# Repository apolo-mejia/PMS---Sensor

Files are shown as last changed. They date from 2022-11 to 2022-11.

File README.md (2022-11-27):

# PMS_Sensor
Power manage System for Microcontrolles ans sensors, in the scope of Syracuza proyect. 
Features:
- Automatic connetion/disconnection, from Li-ION battery protection,
- Automatic disconnection a battery when a external alimentation is provided,
- Compatible with Energy Harvest, <br>
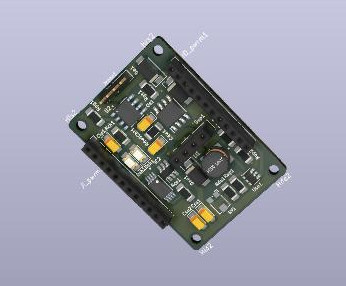
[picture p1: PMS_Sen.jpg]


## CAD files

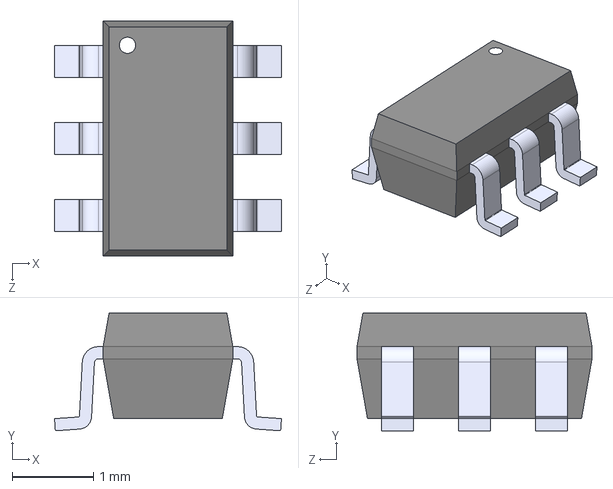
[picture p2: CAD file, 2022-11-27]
DW01A/DW01A.step
2.80 x 1.45 x 2.90 mm

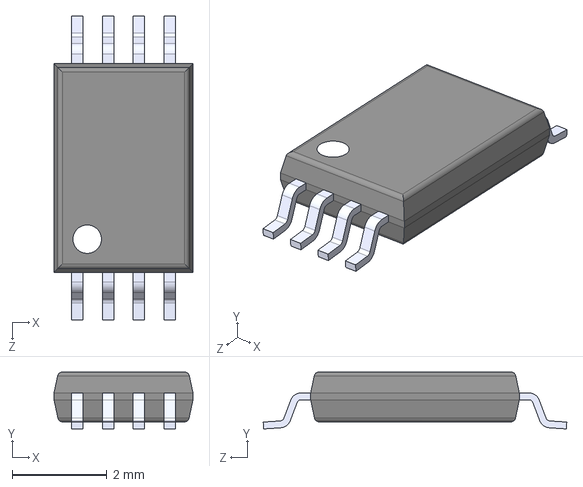
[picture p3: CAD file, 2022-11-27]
FS8205A/FS8205A.step
2.93 x 1.20 x 6.40 mm

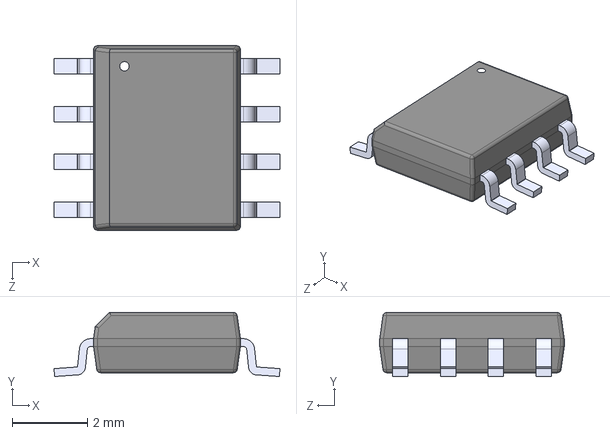
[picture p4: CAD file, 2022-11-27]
TP4056/TP4056.step
6.00 x 1.70 x 4.90 mm

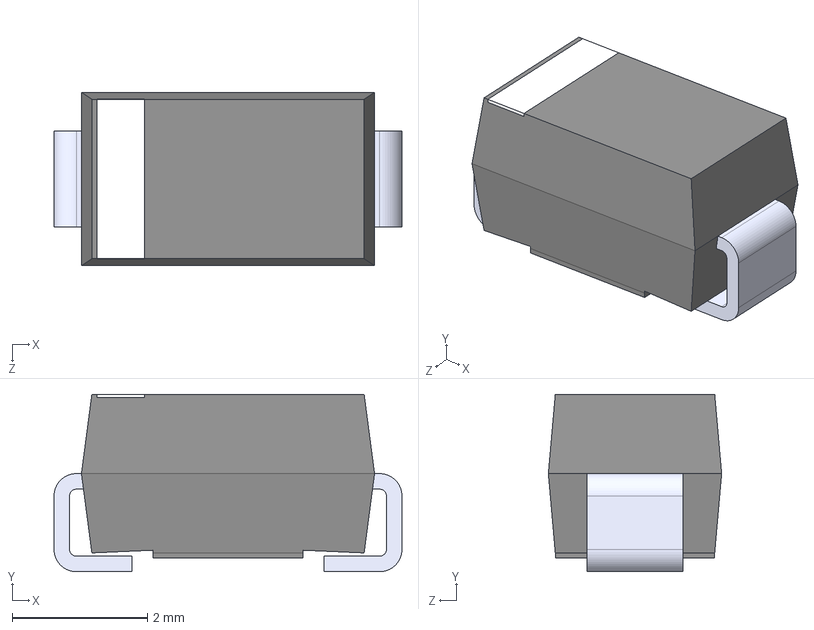
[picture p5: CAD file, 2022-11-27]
US1M-13/US1M-13.step
5.14 x 2.62 x 2.56 mm

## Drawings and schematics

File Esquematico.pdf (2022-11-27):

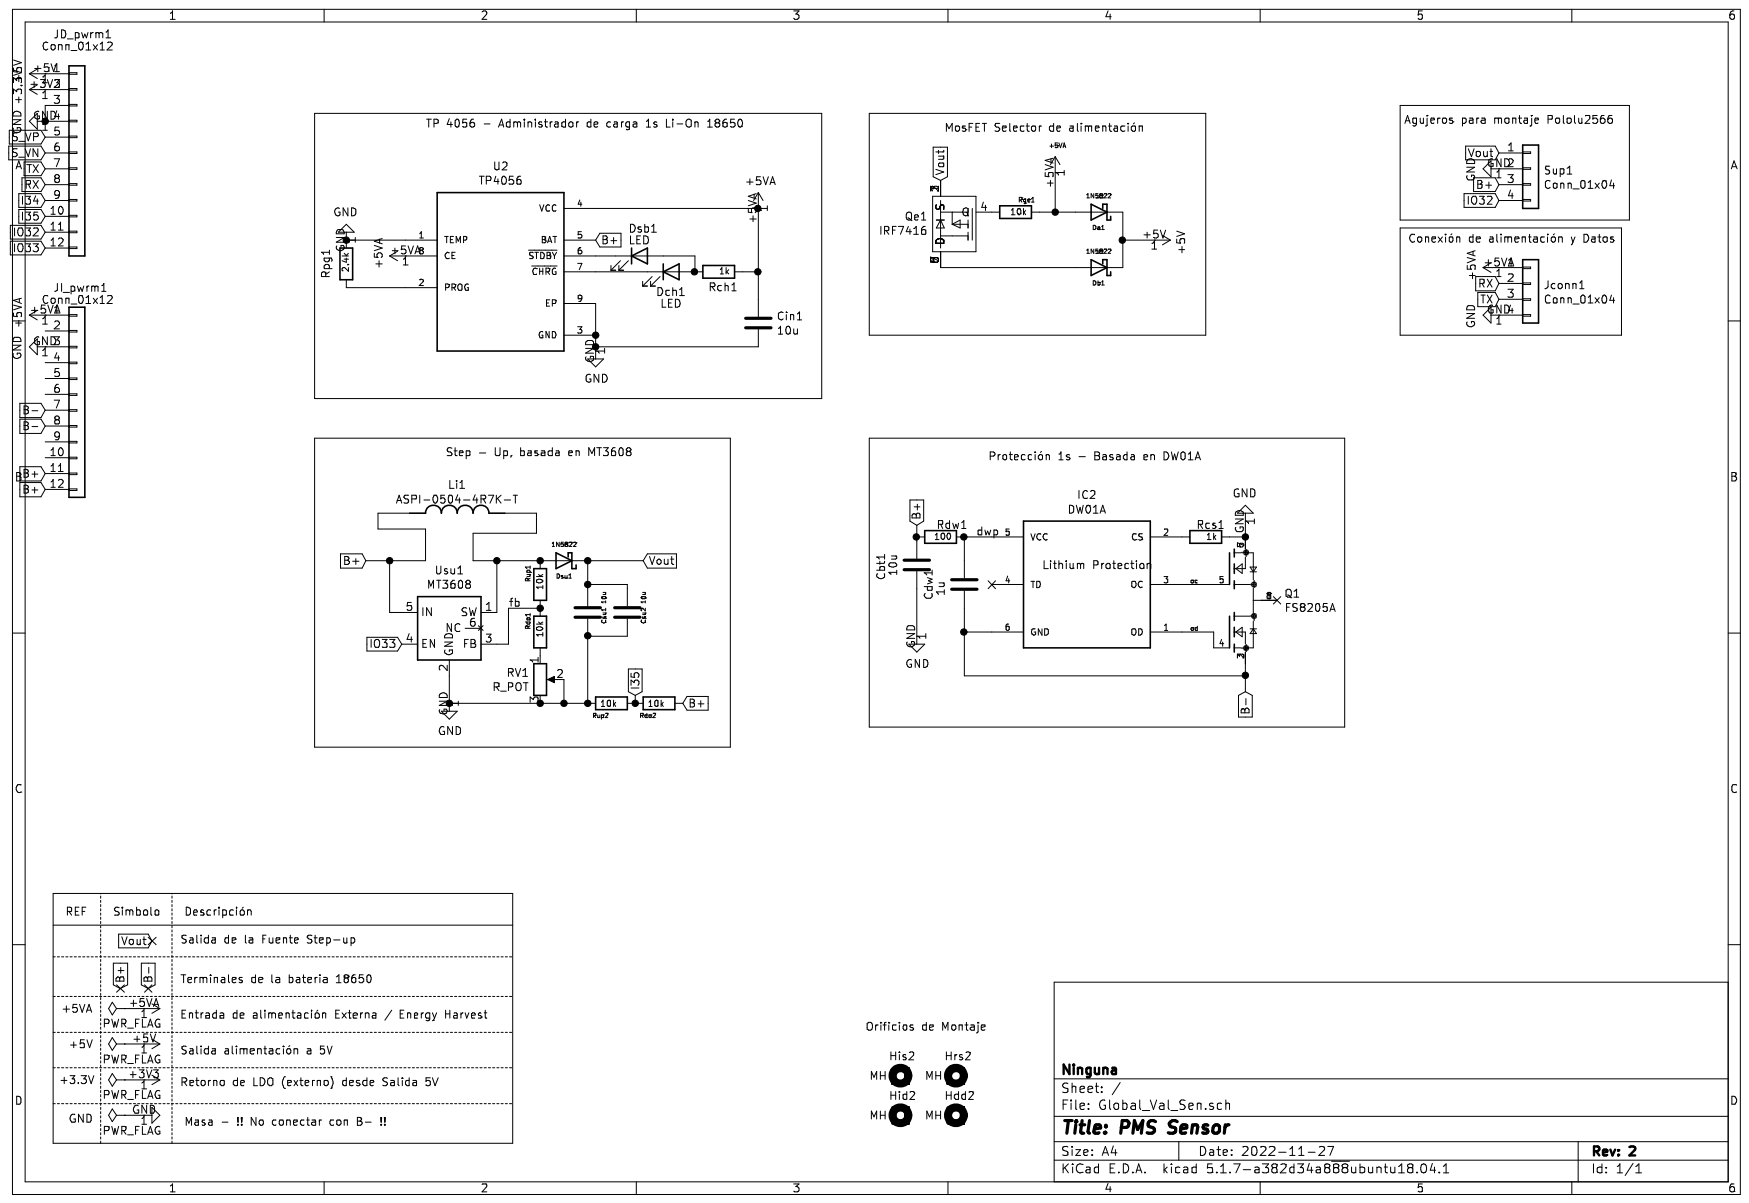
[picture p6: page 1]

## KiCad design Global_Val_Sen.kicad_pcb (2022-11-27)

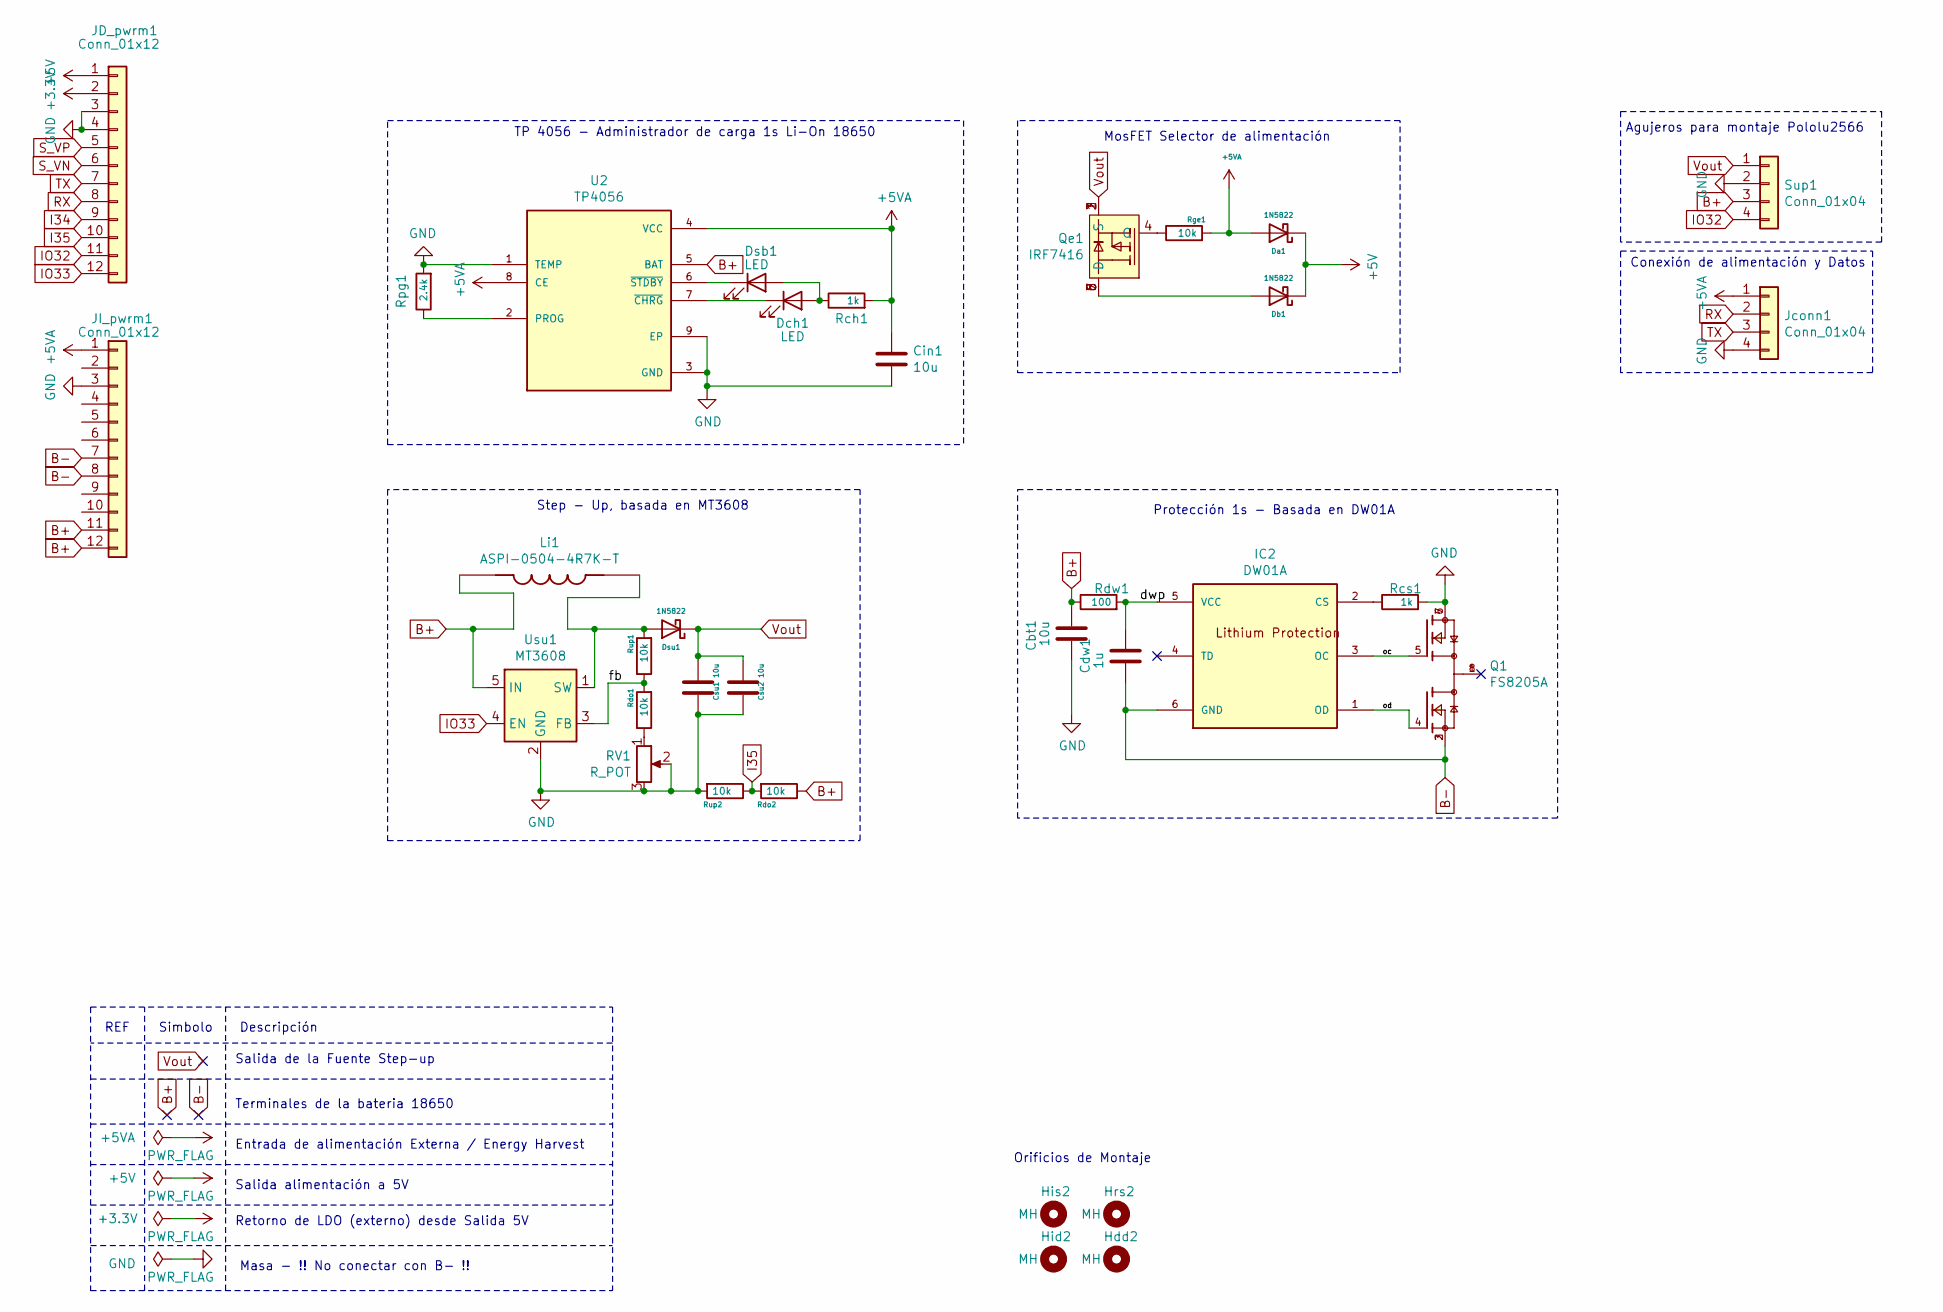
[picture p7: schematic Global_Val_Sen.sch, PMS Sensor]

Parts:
Cbt1: 10u; CP_EIA-3216-10_Kemet-I_Pad1.58x1.35mm_HandSolder
Cdw1: 1u; CP_EIA-3216-10_Kemet-I_Pad1.58x1.35mm_HandSolder
Cin1: 10u; CP_EIA-3216-10_Kemet-I_Pad1.58x1.35mm_HandSolder
Csu1, Csu2: 10u; CP_EIA-3216-10_Kemet-I_Pad1.58x1.35mm_HandSolder
Da1: 1N5822; D_SMA
Db1: 1N5822; D_SMA
Dch1: LED; LED_1206_3216Metric_Castellated
Dsb1: LED; LED_1206_3216Metric_Castellated
Dsu1: 1N5822; D_SMA
Hdd2: MH; MountingHole_2.2mm_M2_DIN965
Hid2: MH; MountingHole_2.2mm_M2_DIN965
His2: MH; MountingHole_2.2mm_M2_DIN965
Hrs2: MH; MountingHole_2.2mm_M2_DIN965
IC2: DW01A; SOT-23-6_Handsoldering
JD_pwrm1: Conn_01x12; PinSocket_1x12_P2.00mm_Vertical
JI_pwrm1: Conn_01x12; PinSocket_1x12_P2.00mm_Vertical
Jconn1: Conn_01x04; PinHeader_1x04_P2.00mm_Vertical
Li1: ASPI-0504-4R7K-T; IND_ASPI-0504-4R7K-T; PARTREV 06.24.13
Q1: FS8205A; SOP65P640X120-8N; PARTREV 1.7
Qe1: IRF7416; SO-8_3.9x4.9mm_P1.27mm
RV1: R_POT; Potentiometer_Bourns_TC33X_Vertical
Rch1: 1k; R_1206_3216Metric_Pad1.30x1.75mm_HandSolder
Rcs1: 1k; R_1206_3216Metric_Pad1.30x1.75mm_HandSolder
Rdo1, Rdo2: 10k; R_1206_3216Metric_Pad1.30x1.75mm_HandSolder
Rdw1: 100; R_1206_3216Metric_Pad1.30x1.75mm_HandSolder
Rge1: 10k; R_1206_3216Metric_Pad1.30x1.75mm_HandSolder
Rpg1: 2.4k; R_1206_3216Metric_Pad1.30x1.75mm_HandSolder
Rup1, Rup2: 10k; R_1206_3216Metric_Pad1.30x1.75mm_HandSolder
Sup1: Conn_01x04; PinSocket_1x04_P2.54mm_Vertical
U2: TP4056; SOP127P600X175-9N
Usu1: MT3608; SOT-23-6

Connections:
+3V3: JD_pwrm1.2
+5V: Da1.1 (K), Db1.1 (K), JD_pwrm1.1
+5VA: Cin1.1, Da1.2 (A), JI_pwrm1.1, Jconn1.1, Rch1.2, Rge1.2, U2.4 (VCC), U2.8 (CE)
/dwp: Cdw1.1, IC2.5 (VCC), Rdw1.2
/fb: Rdo1.2, Rup1.1, Usu1.3 (FB)
/oc: IC2.3 (OC), Q1.5
/od: IC2.1 (OD), Q1.4
B+: Cbt1.1, JI_pwrm1.11, JI_pwrm1.12, Li1.1, Rdo2.1, Rdw1.1, Sup1.3, U2.5 (BAT), Usu1.5 (IN)
B-: Cdw1.2, IC2.6 (GND), JI_pwrm1.7, JI_pwrm1.8, Q1.2, Q1.3
I34: JD_pwrm1.9
I35: JD_pwrm1.10, Rdo2.2, Rup2.1
IO32: JD_pwrm1.11, Sup1.4
IO33: JD_pwrm1.12, Usu1.4 (EN)
unnamed: Db1.2 (A), Qe1.5 (D), Qe1.6 (D), Qe1.7 (D), Qe1.8 (D)
unnamed: Dch1.1 (K), U2.7 (~CHRG)
unnamed: Dch1.2 (A), Dsb1.2 (A), Rch1.1
unnamed: Dsb1.1 (K), U2.6 (~STDBY)
unnamed: Dsu1.2 (A), Li1.2, Rup1.2, Usu1.1 (SW)
unnamed: IC2.2 (CS), Rcs1.1
unnamed: Q1.1, Q1.8
unnamed: Qe1.4 (G), Rge1.1
unnamed: RV1.1, Rdo1.1
unnamed: Rpg1.1, U2.2 (PROG)
RX: JD_pwrm1.8, Jconn1.2
S_VN: JD_pwrm1.6
S_VP: JD_pwrm1.5
TX: JD_pwrm1.7, Jconn1.3
Vout: Csu1.1, Csu2.1, Dsu1.1 (K), Qe1.1 (S), Qe1.2 (S), Qe1.3 (S), Sup1.1

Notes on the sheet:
MosFET Selector de alimentación
Orificios de Montaje
Entrada de alimentación Externa / Energy Harvest
Salida alimentación a 5V
Retorno de LDO (externo) desde Salida 5V
TP 4056 - Administrador de carga 1s Li-On 18650
Step - Up, basada en MT3608
Protección 1s - Basada en DW01A
Agujeros para montaje Pololu2566
Terminales de la bateria 18650
Salida de la Fuente Step-up
Masa - !! No conectar con B- !!
REF
Simbolo
Descripción
Conexión de alimentación y Datos

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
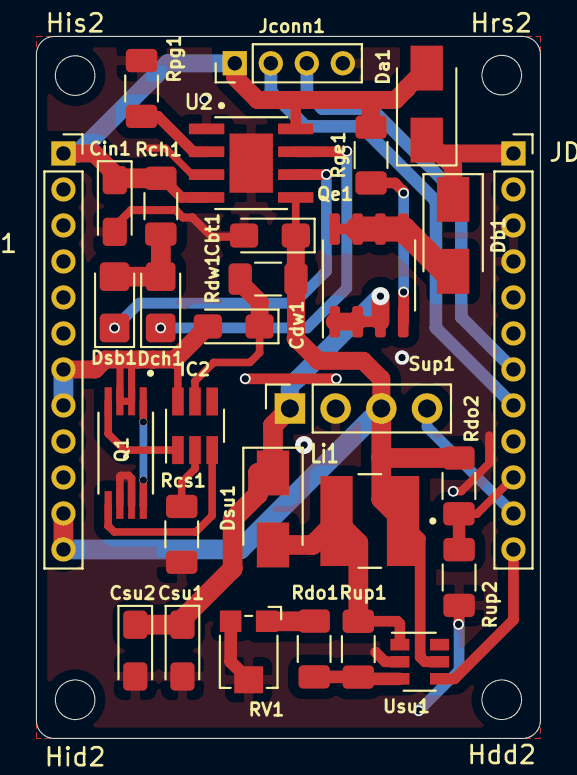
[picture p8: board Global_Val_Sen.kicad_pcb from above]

Board: 2 copper layers, 28.0 x 39.0 mm, 34 parts (0 on the bottom side), 25 nets.
